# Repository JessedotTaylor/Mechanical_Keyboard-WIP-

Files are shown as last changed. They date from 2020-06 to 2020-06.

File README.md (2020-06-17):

These are the work in progress files for the design of a custom mechanical keyboard

Currently working on a POC numpad to test spacing, microcontroller choice, LED wiring and control, and other features.

Current working version for numpad - 'discipad-ESP32'
PCB files were designed in KiCad

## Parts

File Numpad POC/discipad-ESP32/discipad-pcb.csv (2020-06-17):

Id | Designator | Package | Quantity | Designation | Supplier and ref
1 | REF**,REF**,REF** | Stabilizer_MX_2u | 3 | Stabilizer_MX_2u
2 | REF**,REF**,REF**,REF**,REF**,REF**,REF**,REF**,REF**,REF**,REF**,REF**,REF**,REF**,REF**,REF**,REF**,REF**,REF**,REF**,REF** | Kailh_socket_MX | 21 | Kailh_socket_MX
3 | D70,D69,D68,D67,D66,D65,D64,D63,D58,D57,D56,D55,D54,D53,D52,D51,D50,D49,D48,D47,D46,D45,D44,D43,D42,D41,D40,D39,D38,D37,D36,D35,D34,D20,D21,D22,D23,D24,D25,D26,D27,D28,D29,D30,D31,D32,D33 | LED_WS2812B_PLCC4_5.0x5.0mm_P3.2mm | 47 | WS2812B
4 | SW21 | SW_CuK_JS202011AQN_DPDT_Angled | 1 | ON
5 | J3 | PinSocket_1x14_P2.54mm_Vertical | 1 | LCD Header 1x14
6 | J2 | PinSocket_1x15_P2.54mm_Vertical | 1 | 1x15 LH UD NodeMCU
7 | J1 | PinSocket_1x15_P2.54mm_Vertical | 1 | 1x15 RH UD NodeMCU
8 | U3 | SOT-363_SC-70-6 | 1 | LTC3525-5
9 | U2 | SOT-23-5 | 1 | MCP73831-2-OT
10 | R1 | R_Axial_DIN0204_L3.6mm_D1.6mm_P5.08mm_Horizontal | 1 | 10K
11 | L1 | L_Axial_L5.3mm_D2.2mm_P7.62mm_Horizontal_Vishay_IM-1 | 1 | 10u
12 | J4 | JST_EH_S2B-EH_1x02_P2.50mm_Horizontal | 1 | 3.7V Bat 1x2
13 | D61,D60 | D_SOD123_axial | 2 | 1N5820
14 | C8 | C_Disc_D4.3mm_W1.9mm_P5.00mm | 1 | 4.7u
15 | C7 | C_Disc_D4.3mm_W1.9mm_P5.00mm | 1 | 22uF / 6.3V
16 | C6 | C_Disc_D4.3mm_W1.9mm_P5.00mm | 1 | 1u
17 | D120,D119,D19,D18,D1,D2,D3,D4,D5,D6,D7,D8,D9,D10,D11,D12,D13,D14,D15,D16,D17 | D_SOD123_axial | 21
18 | C3 | CP_Radial_D4.0mm_P1.50mm | 1 | 4.7u

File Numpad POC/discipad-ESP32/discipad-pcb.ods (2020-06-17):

Id | Designator | Package | Quantity | Designation | Supplier | Cost | Quantity | Weblink
1 | SW21 | SW_CuK_JS202011AQN_DPDT_Angled | 1 | ON | Mouser | 0.787 | 1 | https://nz.mouser.com/ProductDetail/611-JS202011AQN
2 | J3 | PinSocket_1x14_P2.54mm_Vertical | 1 | LCD Header 1x14 | Aliexpress | 8.71 | 1 | https://www.aliexpress.com/item/32949841210.html?scm_id=1007.13339.146401.0&scm-url=1007.13339.146401.0
3 | J2 | PinSocket_1x15_P2.54mm_Vertical | 1 | 1x15 LH UD NodeMCU | Mouser | 1.8 | 1 | https://nz.mouser.com/ProductDetail/538-22-28-4360
4 | J1 | PinSocket_1x15_P2.54mm_Vertical | 1 | 1x15 RH UD NodeMCU | Above
5 | REF**,REF**,REF** | Stabilizer_MX_2u | 3 | Stabilizer_MX_2u
6 | REF**,REF**,REF**,REF**,REF**,REF**,REF**,REF**,REF**,REF**,REF**,REF**,REF**,REF**,REF**,REF**,REF**,REF**,REF**,REF**,REF** | Kailh_socket_MX | 21 | Kailh_socket_MX | Aliexpress | 11.83 | 50 | https://www.aliexpress.com/item/32951252318.html?scm_id=1007.14976.158757.0&scm-url=1007.14976.158757.0
7 | U3 | SOT-363_SC-70-6 | 1 | LTC3525-5 | Mouser | 7.98 | 1 | https://nz.mouser.com/ProductDetail/Analog-Devices-Linear-Technology/LTC3525ESC6-5TRMPBF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
8 | U2 | SOT-23-5 | 1 | MCP73831-2-OT | Mouser | 0.98 | 1 | https://nz.mouser.com/ProductDetail/Microchip-Technology/MCP73831T-2ACI-OT?qs=yUQqVecv4qvbBQBGbHx0Mw%3D%3D
9 | R1 | R_Axial_DIN0204_L3.6mm_D1.6mm_P5.08mm_Horizontal | 1 | 2K
10 | L1 | L_Axial_L5.3mm_D2.2mm_P7.62mm_Horizontal_Vishay_IM-1 | 1 | 10uH
11 | J4 | JST_EH_S2B-EH_1x02_P2.50mm_Horizontal | 1 | 3.7V Bat 1x2 | Aliexpress | 5 | 10 | https://www.aliexpress.com/item/32903975537.html
12 | D61,D60 | D_SOD123_axial | 2 | 1N5820 | Mouser | 1.14 | 2 | https://nz.mouser.com/ProductDetail/ON-Semiconductor-Fairchild/1N5820?qs=Ro3gc6G1sTlq1RepcfDGzA%3D%3D
13 | C8 | C_Disc_D4.3mm_W1.9mm_P5.00mm | 1 | 4.7u
14 | C7 | C_Disc_D4.3mm_W1.9mm_P5.00mm | 1 | 22uF / 6.3V | Mouser | 2.92 | 1 | https://nz.mouser.com/ProductDetail/KEMET/T356D226K006AT?qs=QWS%252BnixhnkPm8UGzAsFwiQ%3D%3D
15 | C6 | C_Disc_D4.3mm_W1.9mm_P5.00mm | 1 | 1u | Mouser | 2.75 | 1 | https://nz.mouser.com/ProductDetail/Vishay-Sprague/173D105X9025UWE3
16 | D58,D57,D56,D55,D54,D53,D52,D51,D50,D49,D48,D47,D46,D45,D44,D43,D42,D41,D40,D39,D38,D37,D36,D35,D34,D20,D21,D22,D23,D24,D25,D26,D27,D28,D29,D30,D31,D32,D33 | LED_WS2812B_PLCC4_5.0x5.0mm_P3.2mm | 47 | WS2812B | Aliexpress | 8.36 | 50 | https://www.aliexpress.com/item/32641663497.html
17 | D120,D119,D19,D18,D1,D2,D3,D4,D5,D6,D7,D8,D9,D10,D11,D12,D13,D14,D15,D16,D17 | D_SOD123_axial | 21 |  | Mouser | 0.223 | 50 | https://nz.mouser.com/ProductDetail/Vishay-Semiconductors/BAW76-TAP?qs=WLTup5mM6hiyZGq01G5wWg%3D%3D
18 | C3 | CP_Radial_D4.0mm_P1.50mm | 1 | 4.7u
 |  |  |  |  | Aliexpress | 25.23 | 24 | https://www.aliexpress.com/item/32950361232.html

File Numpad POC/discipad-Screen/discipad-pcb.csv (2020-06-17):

Id | Designator | Package | Quantity | Designation | Supplier and ref
1 | REF**,REF**,REF** | Stabilizer_MX_2u | 3 | Stabilizer_MX_2u
2 | Y1 | Crystal_HC49-4H_Vertical | 1 | Crystal
3 | REF**,REF**,REF**,REF**,REF**,REF**,REF**,REF**,REF**,REF**,REF**,REF**,REF**,REF**,REF**,REF**,REF**,REF**,REF**,REF**,REF** | Kailh_socket_MX | 21 | Kailh_socket_MX
4 | J2 | PinSocket_2x03_P2.54mm_Vertical | 1 | ISP 2x3
5 | SW21 | SW_DIP_SPSTx01_Slide_6.7x4.1mm_W6.73mm_P2.54mm_LowProfile_JPin | 1 | ON
6 | U3 | SOT-363_SC-70-6 | 1 | LTC3525-5
7 | U2 | SOT-23-5 | 1 | MCP73831-2-OT
8 | R2 | R_Axial_DIN0204_L3.6mm_D1.6mm_P5.08mm_Horizontal | 1 | 1K
9 | R1,R6 | R_Axial_DIN0204_L3.6mm_D1.6mm_P5.08mm_Horizontal | 2 | 10K
10 | L1 | L_Axial_L5.3mm_D2.2mm_P7.62mm_Horizontal_Vishay_IM-1 | 1 | 10u
11 | J4 | JST_EH_S2B-EH_1x02_P2.50mm_Horizontal | 1 | 3.7V Bat 1x2
12 | D61,D60 | D_SOD123_axial | 2 | 1N5820
13 | D59 | LED_D3.0mm | 1 | LED (red)
14 | C8 | C_Disc_D4.3mm_W1.9mm_P5.00mm | 1 | 4.7u
15 | C7 | C_Disc_D4.3mm_W1.9mm_P5.00mm | 1 | 22uF / 6.3V
16 | C6 | C_Disc_D4.3mm_W1.9mm_P5.00mm | 1 | 1u
17 | J3 | PinSocket_1x14_P2.54mm_Vertical | 1 | LCD Header 1x14
18 | D58,D57,D56,D55,D54,D53,D52,D51,D50,D49,D48,D47,D46,D45,D44,D43,D42,D41,D40,D39,D38,D37,D36,D35,D34,D20,D21,D22,D23,D24,D25,D26,D27,D28,D29,D30,D31,D32,D33 | LED_WS2812B_PLCC4_5.0x5.0mm_P3.2mm | 39 | WS2812B
19 | D120,D119,D19,D18,D1,D2,D3,D4,D5,D6,D7,D8,D9,D10,D11,D12,D13,D14,D15,D16,D17 | D_SOD123_axial | 21
20 | BOOT1 | SW_PUSH_6mm | 1 | BOOT1
21 | C1,C2 | C_Disc_D3.0mm_W1.6mm_P2.50mm | 2 | 22p
22 | C3 | CP_Radial_D4.0mm_P1.50mm | 1 | 4.7u
23 | C4,C5 | C_Disc_D4.3mm_W1.9mm_P5.00mm | 2 | 0.1u
24 | J1 | USB3_A_Molex_48393-001 | 1 | USB_A
25 | RESET1 | SW_PUSH_6mm | 1 | RESET1
26 | U1 | TQFP-44_10x10mm_P0.8mm | 1 | ATmega32U4RC-AU

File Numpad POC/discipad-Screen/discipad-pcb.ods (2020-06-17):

Id | Designator | Package | Quantity | Designation | Supplier | Cost | Quantity | Weblink
1 | REF**,REF**,REF** | Stabilizer_MX_2u | 3 | Stabilizer_MX_2u
2 | Y1 | Crystal_HC49-4H_Vertical | 1 | Crystal | Mouser | 1.1 | 1 | https://nz.mouser.com/Passive-Components/Frequency-Control-Timing-Devices/Crystals/_/N-6zu9f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
3 | REF**,REF**,REF**,REF**,REF**,REF**,REF**,REF**,REF**,REF**,REF**,REF**,REF**,REF**,REF**,REF**,REF**,REF**,REF**,REF**,REF** | Kailh_socket_MX | 21 | Kailh_socket_MX | Aliexpress | 11.83 | 50 | https://www.aliexpress.com/item/32951252318.html?scm_id=1007.14976.158757.0&scm-url=1007.14976.158757.0
4 | J2 | PinSocket_2x03_P2.54mm_Vertical | 1 | ISP 2x3 | From storage
5 | SW21 | SW_DIP_SPSTx01_Slide_6.7x4.1mm_W6.73mm_P2.54mm_LowProfile_JPin | 1 | ON
6 | U3 | SOT-363_SC-70-6 | 1 | LTC3525-5 | Mouser | 7.98 | 1 | https://nz.mouser.com/ProductDetail/Analog-Devices-Linear-Technology/LTC3525ESC6-5TRMPBF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
7 | U2 | SOT-23-5 | 1 | MCP73831-2-OT | Mouser | 0.98 | 1 | https://nz.mouser.com/ProductDetail/Microchip-Technology/MCP73831T-2ACI-OT?qs=yUQqVecv4qvbBQBGbHx0Mw%3D%3D
8 | R2 | R_Axial_DIN0204_L3.6mm_D1.6mm_P5.08mm_Horizontal | 1 | 1K | From storage
9 | R1,R6 | R_Axial_DIN0204_L3.6mm_D1.6mm_P5.08mm_Horizontal | 2 | 10K | From storage
10 | L1 | L_Axial_L5.3mm_D2.2mm_P7.62mm_Horizontal_Vishay_IM-1 | 1 | 10u
11 | J4 | JST_EH_S2B-EH_1x02_P2.50mm_Horizontal | 1 | 3.7V Bat 1x2 | Aliexpress | 5 | 10 | https://www.aliexpress.com/item/32903975537.html
12 | D61,D60 | D_SOD123_axial | 2 | 1N5820 | Mouser | 1.14 | 2 | https://nz.mouser.com/ProductDetail/ON-Semiconductor-Fairchild/1N5820?qs=Ro3gc6G1sTlq1RepcfDGzA%3D%3D
13 | D59 | LED_D3.0mm | 1 | LED (red) | From storage
14 | C8 | C_Disc_D4.3mm_W1.9mm_P5.00mm | 1 | 4.7u
15 | C7 | C_Disc_D4.3mm_W1.9mm_P5.00mm | 1 | 22uF / 6.3V
16 | C6 | C_Disc_D4.3mm_W1.9mm_P5.00mm | 1 | 1u
17 | J3 | PinSocket_1x14_P2.54mm_Vertical | 1 | LCD Header 1x14 | Aliexpress | 8.71 | 1 | https://www.aliexpress.com/item/32949841210.html?scm_id=1007.13339.146401.0&scm-url=1007.13339.146401.0
18 | D58,D57,D56,D55,D54,D53,D52,D51,D50,D49,D48,D47,D46,D45,D44,D43,D42,D41,D40,D39,D38,D37,D36,D35,D34,D20,D21,D22,D23,D24,D25,D26,D27,D28,D29,D30,D31,D32,D33 | LED_WS2812B_PLCC4_5.0x5.0mm_P3.2mm | 39 | WS2812B | Aliexpress | 8.36 | 50 | https://www.aliexpress.com/item/32641663497.html
19 | D120,D119,D19,D18,D1,D2,D3,D4,D5,D6,D7,D8,D9,D10,D11,D12,D13,D14,D15,D16,D17 | D_SOD123_axial | 21 |  | From storage
20 | BOOT1 | SW_PUSH_6mm | 1 | BOOT1 | From storage
21 | C1,C2 | C_Disc_D3.0mm_W1.6mm_P2.50mm | 2 | 22p
22 | C3 | CP_Radial_D4.0mm_P1.50mm | 1 | 4.7u
23 | C4,C5 | C_Disc_D4.3mm_W1.9mm_P5.00mm | 2 | 0.1u
24 | J1 | USB3_A_Molex_48393-001 | 1 | USB_A | Aliexpress | 5 | 20 | https://www.aliexpress.com/item/32872327793.html
25 | RESET1 | SW_PUSH_6mm | 1 | RESET1 | From storage
26 | U1 | TQFP-44_10x10mm_P0.8mm | 1 | ATmega32U4RC-AU | Mouser | 6.96 | 1 | https://nz.mouser.com/ProductDetail/Microchip-Technology-Atmel/ATMEGA32U4RC-AU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
 |  |  |  |  | Aliexpress | 25.23 | 24 | https://www.aliexpress.com/item/32950361232.html

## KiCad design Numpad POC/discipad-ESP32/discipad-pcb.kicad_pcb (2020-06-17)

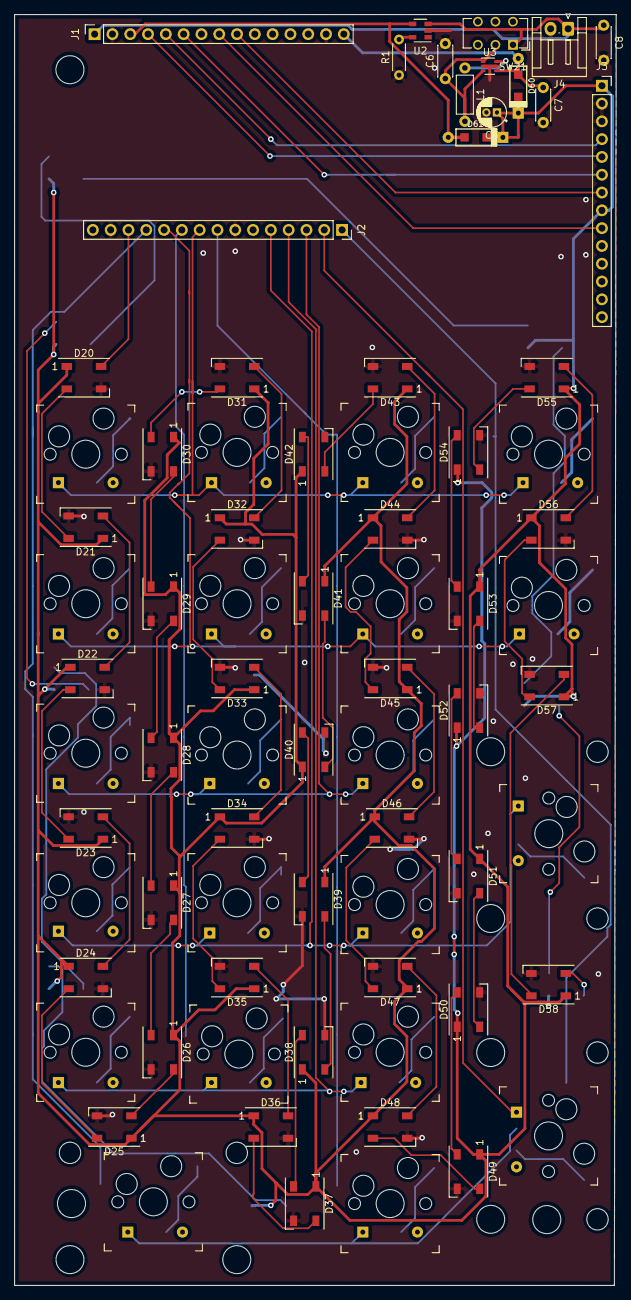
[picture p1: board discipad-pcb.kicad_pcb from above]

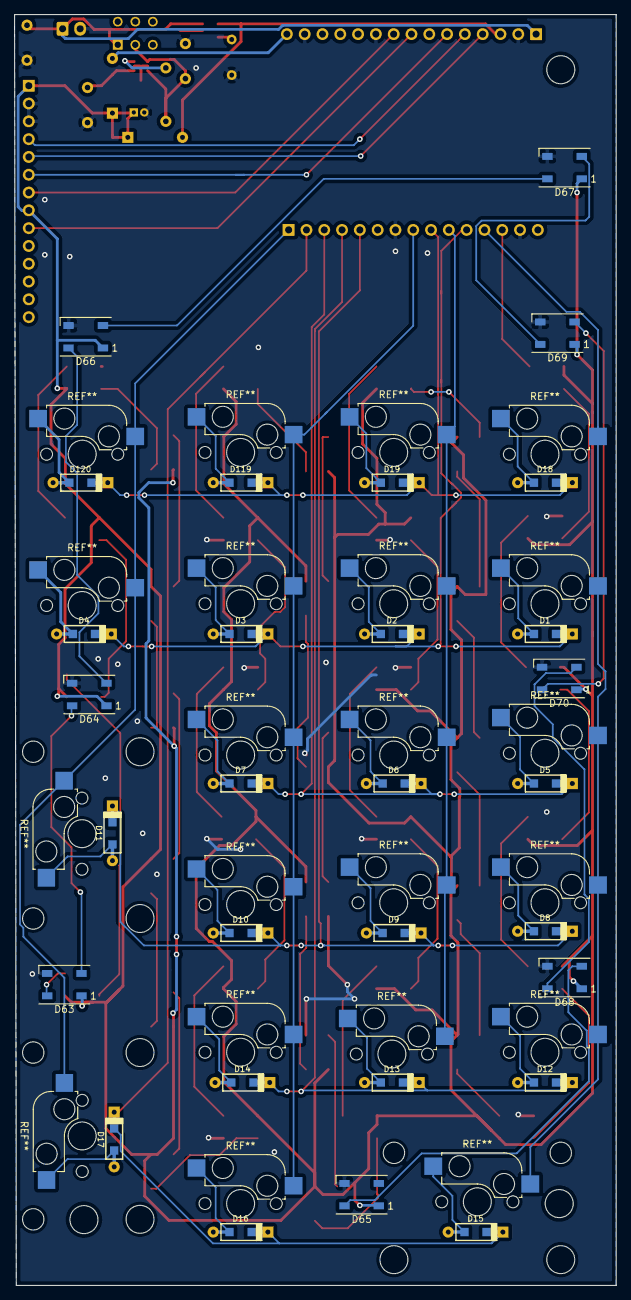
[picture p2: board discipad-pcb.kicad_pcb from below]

Board: 2 copper layers, 85.9 x 181.4 mm, 83 parts (29 on the bottom side), 66 nets.

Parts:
C3: 4.7u; CP_Radial_D4.0mm_P1.50mm
C6: 1u; C_Disc_D4.3mm_W1.9mm_P5.00mm
C7: 22uF / 6.3V; C_Disc_D4.3mm_W1.9mm_P5.00mm
C8: 4.7u; C_Disc_D4.3mm_W1.9mm_P5.00mm
D1, D2, D3, D4, D5, D6, D7, D8, D9, D10, D11, D12, D13, D14, D15, D16, D17, D18, D19, D119, D120: D_SOD123_axial
D20, D21, D22, D23, D24, D25, D26, D27, D28, D29, D30, D31, D32, D33, D34, D35, D36, D37, D38, D39, D40, D41, D42, D43, D44, D45, D46, D47, D48, D49, D50, D51, D52, D53, D54, D55, D56, D57, D58, D63, D64, D65, D66, D67, D68, D69, D70: WS2812B; LED_WS2812B_PLCC4_5.0x5.0mm_P3.2mm
D60, D61: 1N5820; D_SOD123_axial
J1: 1x15 RH UD NodeMCU; PinSocket_1x15_P2.54mm_Vertical
J2: 1x15 LH UD NodeMCU; PinSocket_1x15_P2.54mm_Vertical
J3: LCD Header 1x14; PinSocket_1x14_P2.54mm_Vertical
J4: 3.7V Bat 1x2; JST_EH_S2B-EH_1x02_P2.50mm_Horizontal
L1: 10u; L_Axial_L5.3mm_D2.2mm_P7.62mm_Horizontal_Vishay_IM-1
R1: 2K; R_Axial_DIN0204_L3.6mm_D1.6mm_P5.08mm_Horizontal
SW21: ON; SW_CuK_JS202011AQN_DPDT_Angled
U2: MCP73831-2-OT; SOT-23-5
U3: LTC3525-5; SOT-363_SC-70-6

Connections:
5VREG: C7.1, D60.2, J1.15, U3.4
5VUSB: D61.2, J1.3, U2.4
+5V: C3.1, D20.1, D21.1, D22.1, D23.1, D24.1, D25.1, D26.1, D27.1, D28.1, D29.1, D30.1, D31.1, D32.1, D33.1, D34.1, D35.1, D36.1, D37.1, D38.1, D39.1, D40.1, D41.1, D42.1, D43.1, D44.1, D45.1, D46.1, D47.1, D48.1, D49.1, D50.1, D51.1, D52.1, D53.1, D54.1, D55.1, D56.1, D57.1, D58.1, D60.1, D61.1, D63.1, D64.1, D65.1, D66.1, D67.1, D68.1, D69.1, D70.1, J3.1, J3.8
GND: C3.2, C6.2, C7.2, C8.2, D20.3, D21.3, D22.3, D23.3, D24.3, D25.3, D26.3, D27.3, D28.3, D29.3, D30.3, D31.3, D32.3, D33.3, D34.3, D35.3, D36.3, D37.3, D38.3, D39.3, D40.3, D41.3, D42.3, D43.3, D44.3, D45.3, D46.3, D47.3, D48.3, D49.3, D50.3, D51.3, D52.3, D53.3, D54.3, D55.3, D56.3, D57.3, D58.3, D63.3, D64.3, D65.3, D66.3, D67.3, D68.3, D69.3, D70.3, J1.2, J1.10, J1.14, J2.7, J2.14, J3.2, J3.3, J4.2, R1.1, U2.2, U3.2, U3.5
LCD_RS: J1.4, J3.5
LCD_RST: J1.5, J3.4
LEDin: D20.4, J2.13
MISO: J1.8, J3.9
MOSI: J1.6, J3.6
unnamed: C6.1, L1.2, SW21.2, U3.1, U3.3
unnamed: D20.2, D21.4
unnamed: D21.2, D22.4
unnamed: D22.2, D23.4
unnamed: D23.2, D24.4
unnamed: D24.2, D25.4
unnamed: D25.2, D26.4
unnamed: D26.2, D27.4
unnamed: D27.2, D28.4
unnamed: D28.2, D29.4
unnamed: D29.2, D30.4
unnamed: D30.2, D31.4
unnamed: D31.2, D32.4
unnamed: D32.2, D33.4
unnamed: D33.2, D34.4
unnamed: D34.2, D35.4
unnamed: D35.2, D36.4
unnamed: D36.2, D37.4
unnamed: D37.2, D38.4
unnamed: D38.2, D39.4
unnamed: D39.2, D40.4
unnamed: D40.2, D41.4
unnamed: D41.2, D42.4
unnamed: D42.2, D43.4
unnamed: D43.2, D44.4
unnamed: D44.2, D45.4
unnamed: D45.2, D46.4
unnamed: D46.2, D47.4
unnamed: D47.2, D48.4
unnamed: D48.2, D49.4
unnamed: D49.2, D50.4
unnamed: D50.2, D51.4
unnamed: D51.2, D52.4
unnamed: D52.2, D53.4
unnamed: D53.2, D54.4
unnamed: D54.2, D55.4
unnamed: D55.2, D56.4
unnamed: D56.2, D57.4
unnamed: D57.2, D58.4
unnamed: D63.2, D64.4
unnamed: D64.2, D66.4
unnamed: D65.4, D68.2
unnamed: D66.2, D67.4
unnamed: D67.2, D69.4
unnamed: D68.4, D70.2
unnamed: D69.2, D70.4
unnamed: L1.1, U3.6
unnamed: R1.2, U2.5
SCK: J1.9, J3.7
UNDERGLOW: D58.2, D63.4
VBAT: C8.1, J1.1, J4.1, SW21.1, U2.3
row0: D1.1, D2.1, D3.1, D4.1, J2.11
row1: D5.1, D6.1, D7.1, J2.3
row2: D8.1, D9.1, D10.1, D11.1, J2.5
row3: D12.1, D13.1, D14.1, J2.4
row4: D15.1, D16.1, D17.1, J2.2
row5: D18.1, D19.1, D119.1, D120.1, J2.9
